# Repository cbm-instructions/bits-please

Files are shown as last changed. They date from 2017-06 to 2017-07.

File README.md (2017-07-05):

# bits-please | PlayTable
<div>
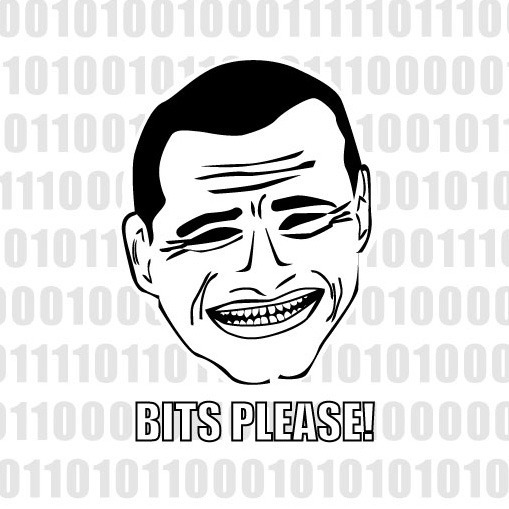
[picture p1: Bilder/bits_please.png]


</div>

## Einleitung
Der PlayTable ist ein Unterhaltungs-/Freizeitgegenstand und wurde von dem Team bits-please entwickelt. Es handelt sich hierbei um einen kleinen Tisch, in dem eine Matrix aus Pixel integriert ist, welche aufleuchten können. Es können bis zu zwei Leuten mit dem Tisch interagieren. Der PlayTable lässt jedes Gamerherz höher schlagen und dient für den Stressabbau des Hochschulalltags und den Zusammenschluss von Studierenden und Mitarbeitern.
 
Der PlayTable kann klassische Arcade-Games wie Tetris oder Pong aufweisen oder einfach nur als Dekoration für den Raum dienen, indem verschiedenste Bilder oder Animationen angezeigt werden.
 
Mit den zwei dazugehörigen Controllern macht das interagieren des Playtable gleich viel mehr Spaß!

### Challenge
Die Welt ist immer im Wandel und entwickelt sich immer weiter. So kommen auch neue Begriffe zu stande wie “Smart City”, der in aller Munde ist. Demzufolge soll es Universitäten geben, von denen man behaupten kann, dass sie eine “Smart University” sind. Die Hochschule Mannheim soll natürlich auch mit der Zeit gehen, weswegen uns die folgende Challenge gestellt wurde:
 
**Wie könnten Menschen in der „Smart HS Mannheim“ durch deren intelligente Geräte und Objekte dabei unterstützt werden angenehmer und spielerischer zu arbeiten?**
 
Aus diesem Grund haben wir uns für die Entwicklung eines “Smart Furniture” entschieden, nämlich für die Entwicklung des PlayTables.

### Point of View
Wie können wir den Studierenden helfen den Hochschulalltag entspannter und kreativer zu gestalten?

## Material und Werkzeug
 
### Material
* Schrumpfschlauch
* Diverse Kabel
* Kabelbinder
* Lötzinn
* Holzleim (Im Idealfall schnelltrocknend)
 
### Werkzeuge
* Bohrer
* Fräsbohrer 
* Lötkolben
* Abisolierzange
* Heißluftgebläse
* Heißklebepistole
* Schraubendreher Kreuzschlitz 
* Gehrungssäge
* Stichsäge
* Lasercutter
* Seitenschneider
* Schere
* Teppichbodenmesser
 
### Elektronik
* Arduino Mega
* Netzteil 5v,30A z.B. ATX-Netzteil 300W 
* Stromkabel Schuko auf Kaltgerätestecker
* 2x Female USB Kabel
* Schrumpfschlauch diverse Größen
* Lötzinn bleifrei
* Klebesockel
* Kabelbinder
* 4 x Widerstände 1.5K Ohm

### Tisch
* Kantholz (34mm x 34mm) benötogte Länge insgesamt 10 x 65 cm
* Spanplatte(65cm x 65cm , Stärke 12mm)
* Plexiglasplatte (65cm x 65cm,Lichtdurchlässigkeit 79%)
* Spaxschrauben 4mm x 60 mm (Für Rahmen)
* Spaxschrauben 3mm x 30 mm (Für Tischplatte)

### Matrix
* 3x Hochdichte Faserplatte (600mm x 45mm x 3mm)
* LED Stripes (60 LED's / m) zugeschnitten zu 16 Stripes a' 32 LED's 
 
### Controller
* Hochdichte Faserplatte (600mm x 45mm x 3mm)
* 8x 16mm Ø Buttons (Bspw von [Exp-Tech](http://www.exp-tech.de/16mm-panel-mount-momentary-pushbutton-yellow))
* 14 Magneten (5mm x 2,5mm x 2,5mm)
* 2 USB Kabel (2m)

## Bauanleitung

### Tischunterkonstruktion



Bauen des Tischs: [Anleitung](https://github.com/cbm-instructions/bits-please/blob/master/Tisch/README.md)

### Matrix

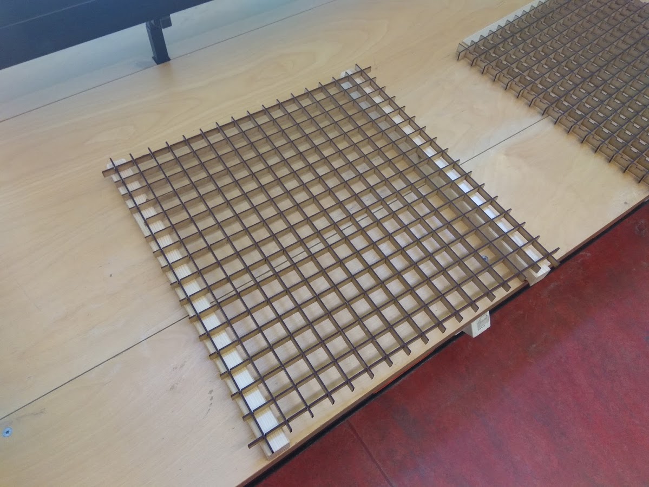
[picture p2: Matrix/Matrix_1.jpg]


Anfertigen der Matrix mit dem Lasercutter: [Anleitung](https://github.com/cbm-instructions/bits-please/blob/master/Matrix/README.md)

### Controller

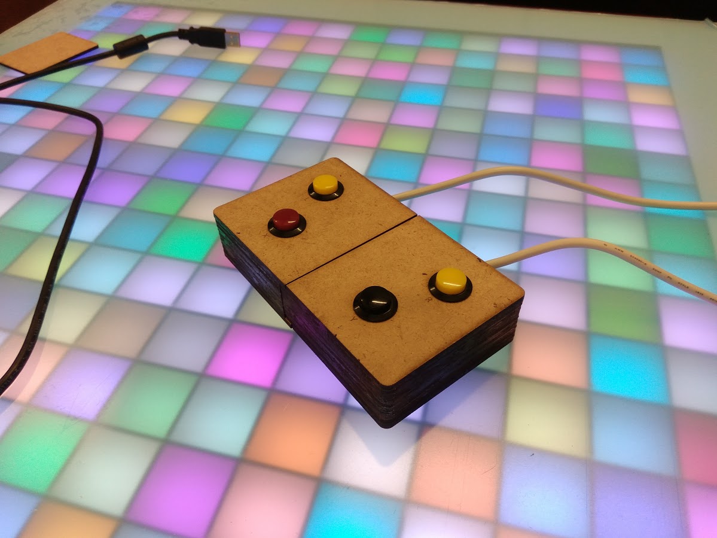
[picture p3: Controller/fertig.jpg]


Anfertigen des Controllers: [Anleitung](https://github.com/cbm-instructions/bits-please/blob/master/Controller/README.md)

### Elektronik

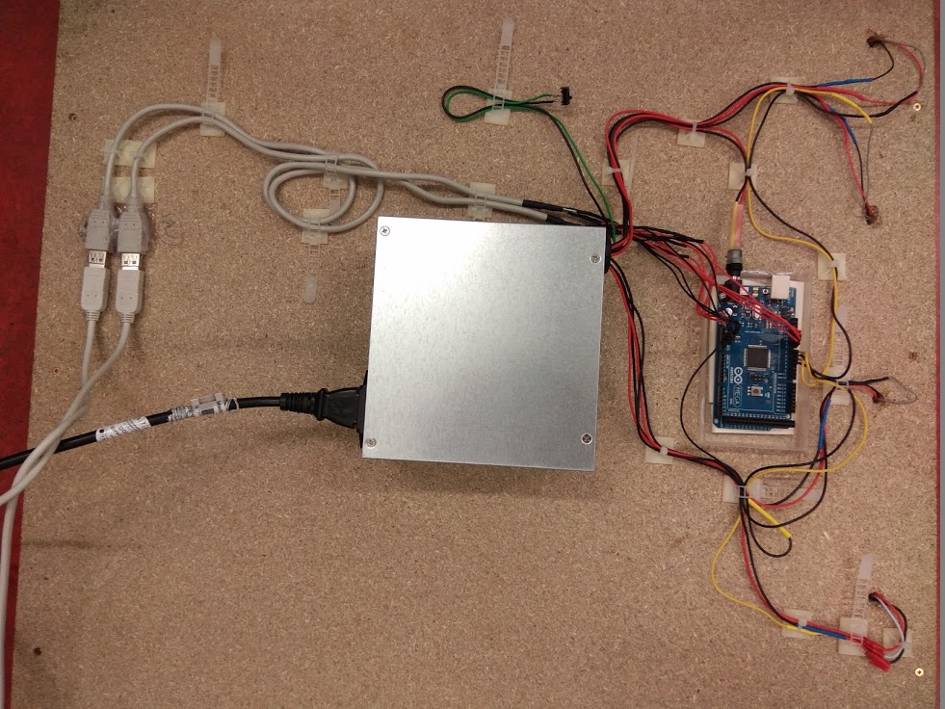
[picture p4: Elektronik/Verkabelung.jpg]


Anleitung zur Elektronik: [Anleitung](https://github.com/cbm-instructions/bits-please/blob/master/Elektronik/README.md)

### Finish

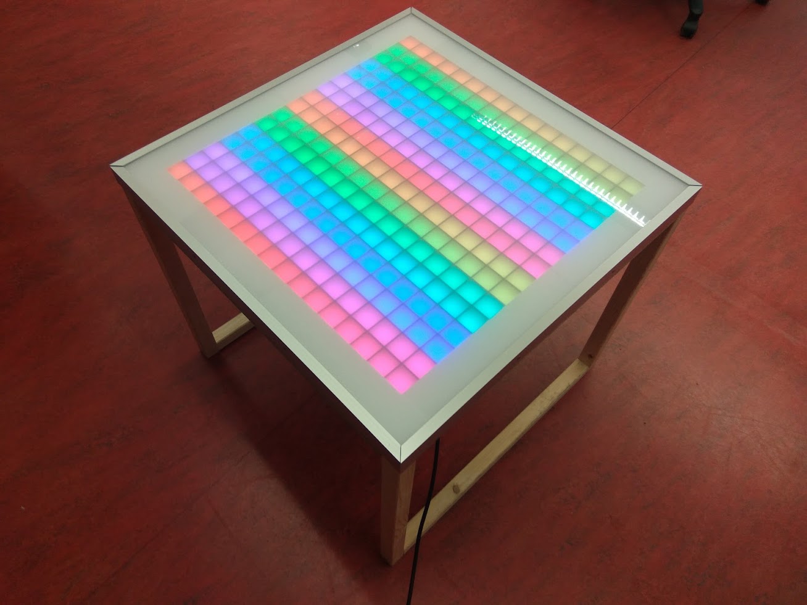
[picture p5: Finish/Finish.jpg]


Fertigstellen des Tischs: [Anleitung](https://github.com/cbm-instructions/bits-please/blob/master/Finish/README.md)

### Code
Die verwendete .ino Datei gibt's hier: [CBM.ino](https://github.com/cbm-instructions/bits-please/blob/master/Code/CBM.ino)<br>

Wer nur die Umsetzungen der einzelnen Spiele möchte findet diese hier:<br>

**Spiele**<br>
* Pong: [Pong](https://github.com/cbm-instructions/bits-please/blob/master/Code/Pong/Pong.c)<br>
* Tetris: [Tetris](https://github.com/cbm-instructions/bits-please/blob/master/Code/Tetris/Tetris.c)<br>  
* Snake: [Snake](https://github.com/cbm-instructions/bits-please/blob/master/Code/Snake/Snake.c)<br>

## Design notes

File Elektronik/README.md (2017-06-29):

Zum öffnen und bearbeiten des Schaltplans wird das Tool "Fritzing" benötigt. 
http://fritzing.org/download/ 
# Elektronik

## Schaltplan
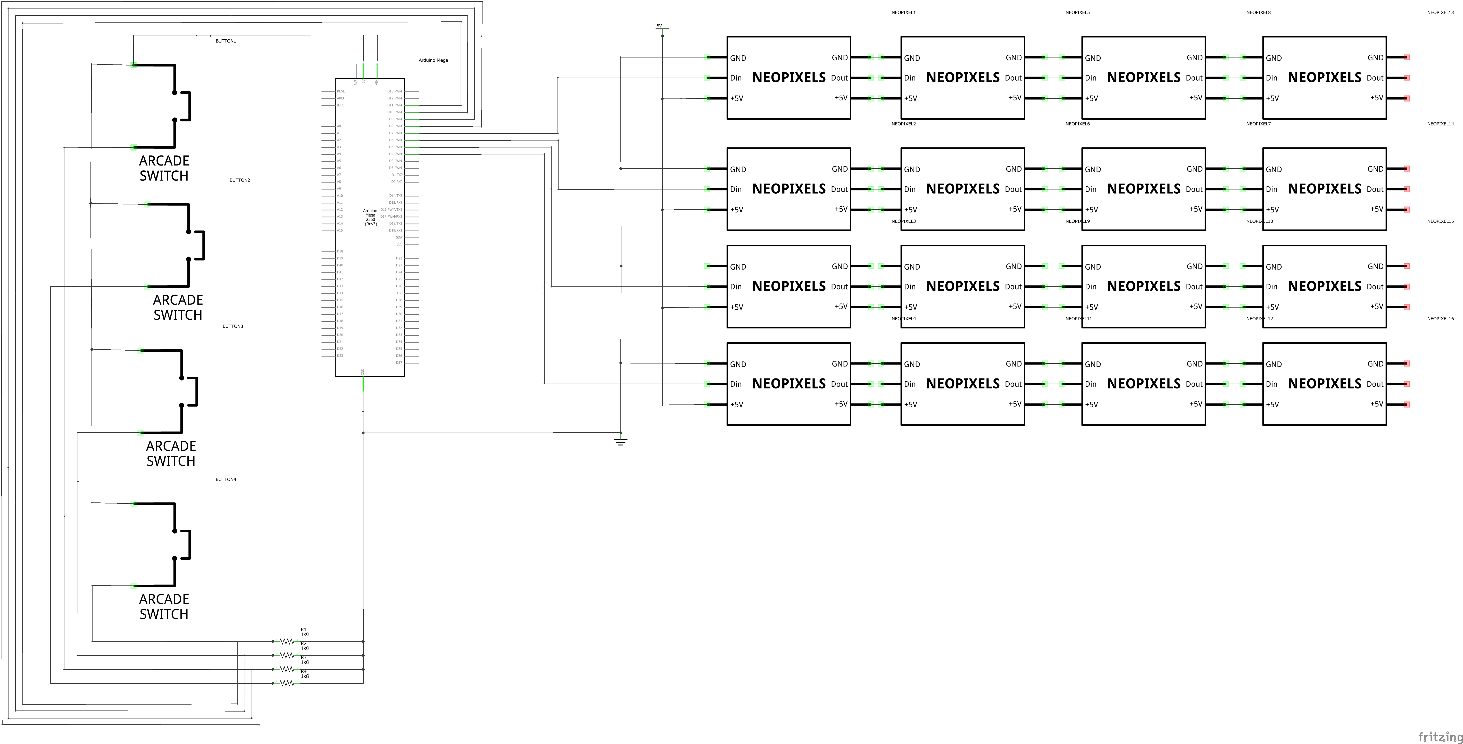
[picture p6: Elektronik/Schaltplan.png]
<br>

Der Schaltplan ist hier zu finden: [Fritzing-File](https://github.com/cbm-instructions/bits-please/blob/master/Schaltplan/Schaltplan.fzz), [Bild](https://github.com/cbm-instructions/bits-please/blob/master/Schaltplan/Schaltplan.png)

## Ansteuerung der LED Stripes
Um alle 16 LED-Stripes ansteuern zu können müssen diese zu vier Viererblöcken mit je 4x32 LED'S(32 LED's = 1 LED-Stripe) verlötet werden. Diese viererblöcke werden jeweils über einen Arduino Ausgang, eine 5V Spannungsversorgung und ein Masserkabel verdrahtet.(Siehe Schaltplan)

<br>

## Stromversorgung 

### AdaFruit NeoPixel am Arduino Mega
Auf die Stromversorgung der einzelnen Pixel muss geachtet werden. <br>
Ein einzelner NeoPixel kann **20mA bis zu 60mA** Strom ziehen, je nach der Einstellung in der Software.

Da wir bei einer 16x16 Pixel Matrix, wobei jeder einzelner Pixel zwei LED NeoPixel besitzt, wird der Strombedarf wie folgt berechnet:<br>

**16 LED Stripes mit jeweils 32 Neopixel, was uns insgesamt auf 512 NeoPixel bringt.**<br>
**Das heißt der Strombedarf liegt bei: 10240mA - 30720mA ~ 10,24A - 30,72A**

### Netzteil
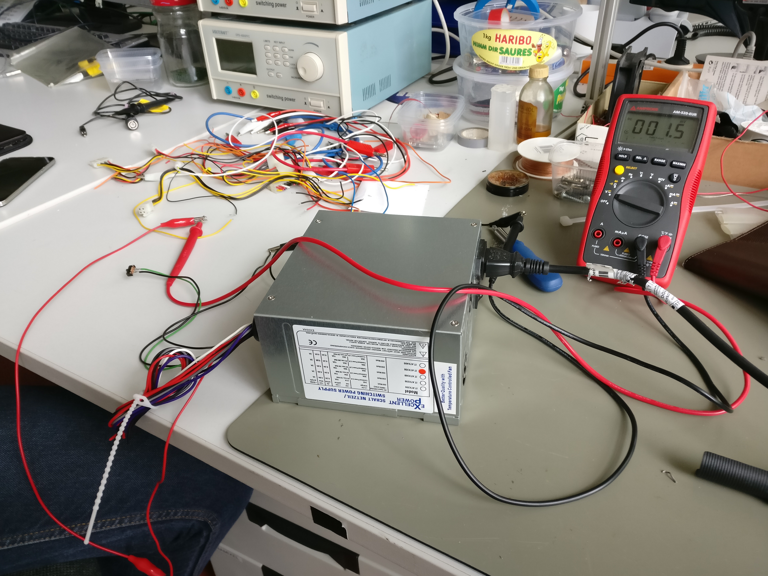
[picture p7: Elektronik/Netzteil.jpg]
<br>

Bei der Verwendung eines ATX Computer Netzteils, werden die nicht verwendeten Kabel entfernt. Benötigt werden nur die roten (5V) Kabel und die schwarzen (Masse)kabel. Das Grüne Kabel (PS_ON) muss mit einem schwarzen Massekabel kurzgeschlossen werden.<br>

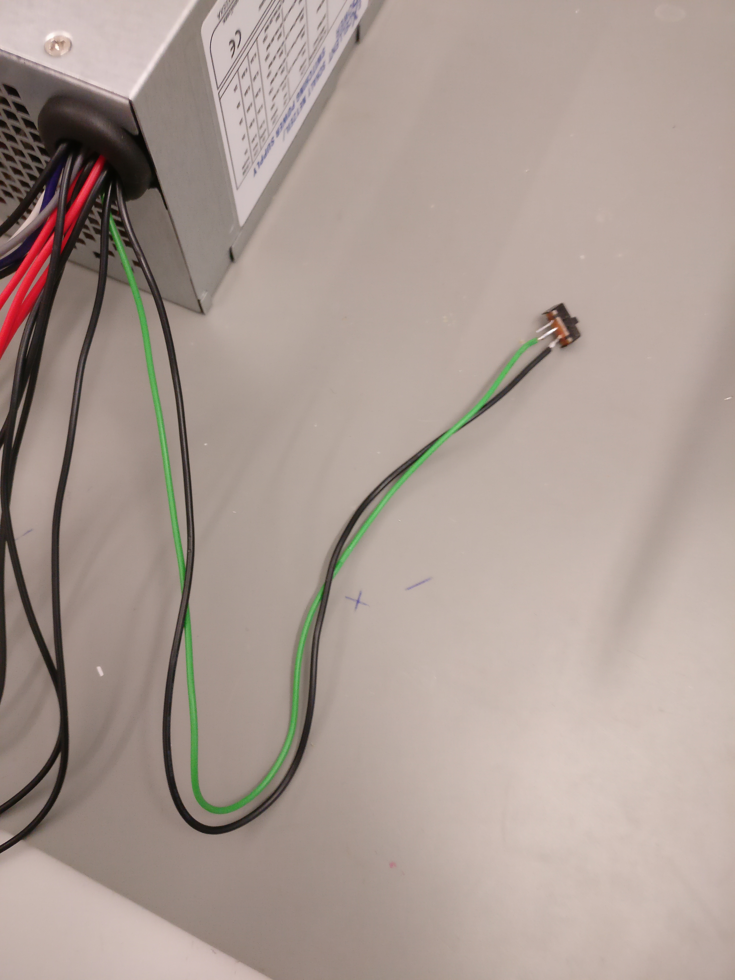
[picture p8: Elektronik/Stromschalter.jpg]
<br>

Die verlöteten Kabel mithilfe von Klebesockel und Kabelbinder an der Tisch Unterseite montieren. Netzteil an unterseite schrauben oder festkleben. Arduino ebenfalls festkleben. 

<br>

Lötstellen und offene Kabelenden mit Schrumpfschlauch isolieren!

<br>

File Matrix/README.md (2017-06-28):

## Matrix
### 1. Lasercutter Zuschnitte anlegen (3 Platten a 60x45cm)
Zum Download der [Illustratordateien](https://github.com/cbm-instructions/bits-please/blob/master/Matrix/Zuschnitt_Matrix.zip)

Dabei darauf achten, dass der Laser stark genug eingestellt ist, sonst können beim Ausbrechen Teile kaputt gehen.

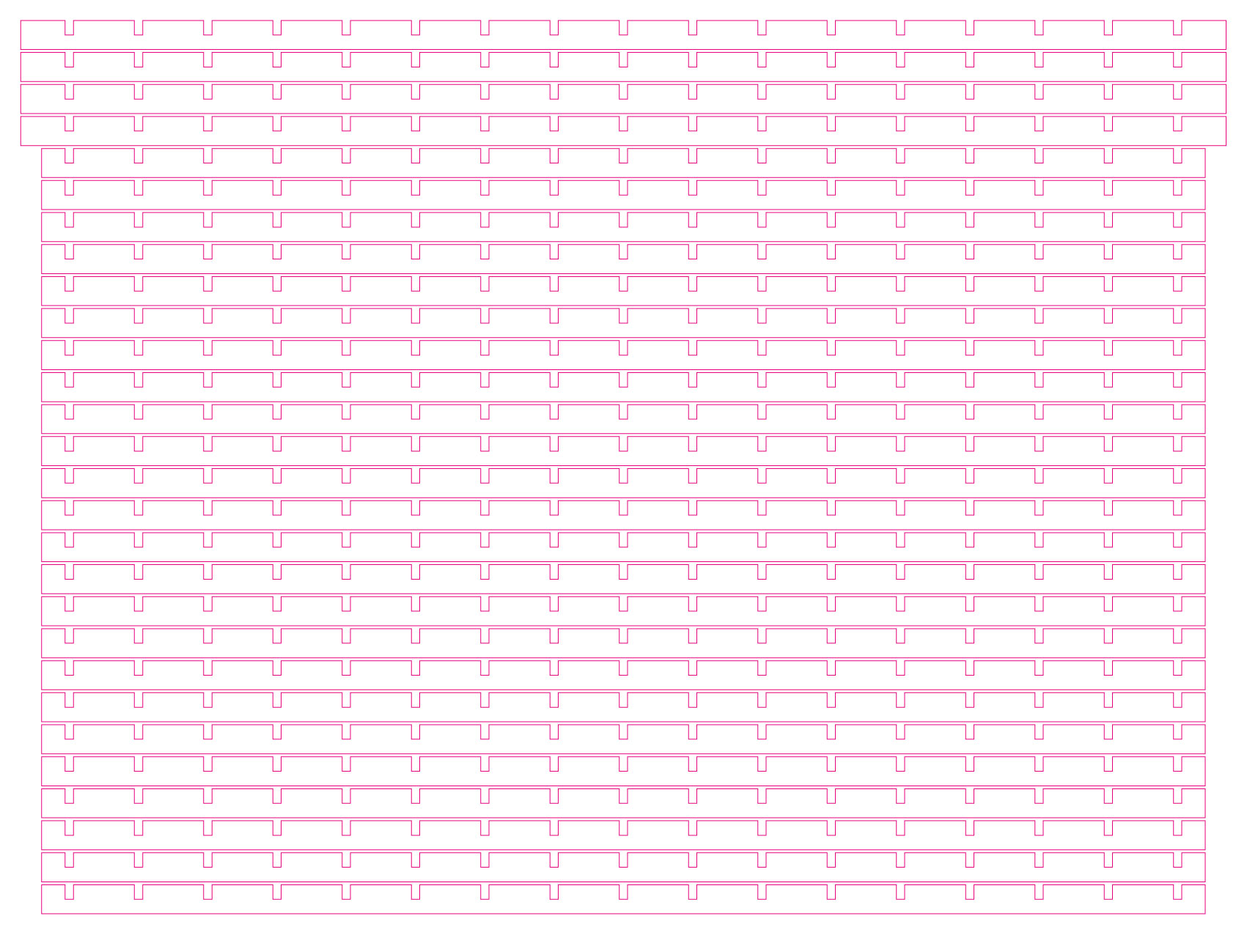
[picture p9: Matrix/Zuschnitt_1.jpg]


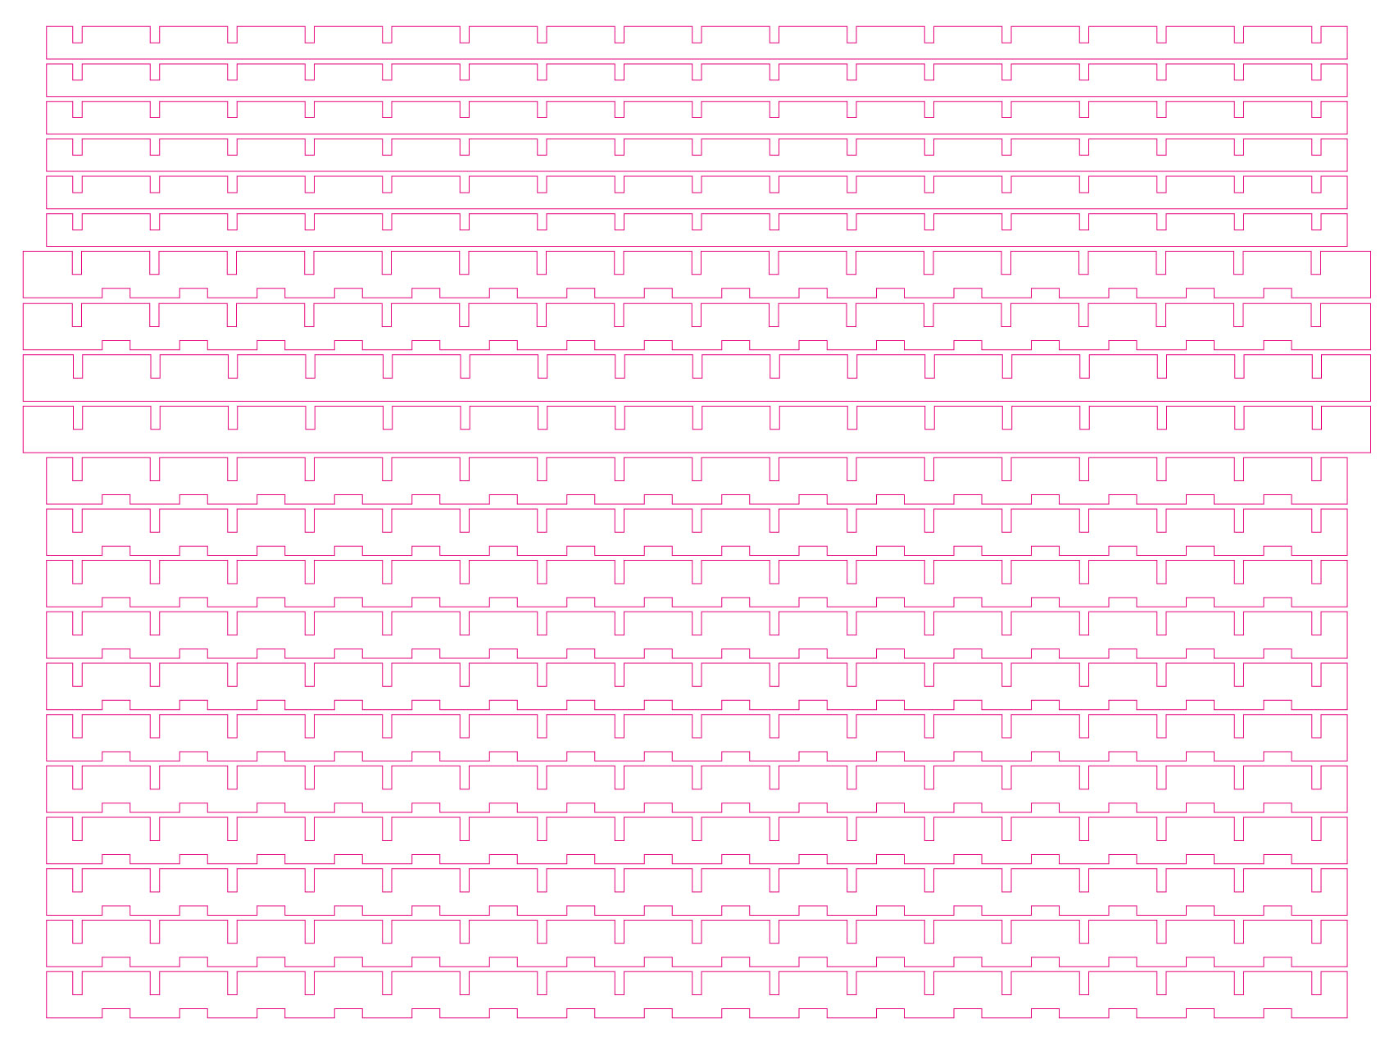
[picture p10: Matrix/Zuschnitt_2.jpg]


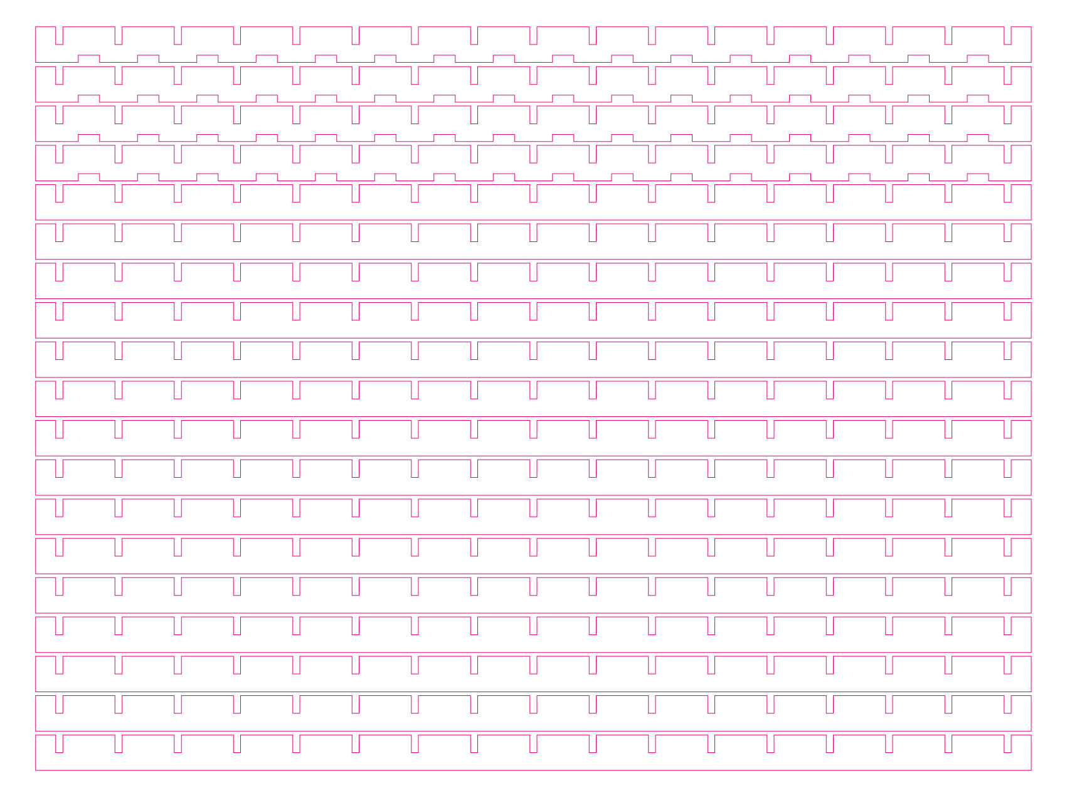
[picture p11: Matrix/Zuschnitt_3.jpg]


### 2. HDF Platten auf 60cm x 45cm zuschneiden
Oder direkt im Baumarkt auf die Größe zuschneiden lassen.

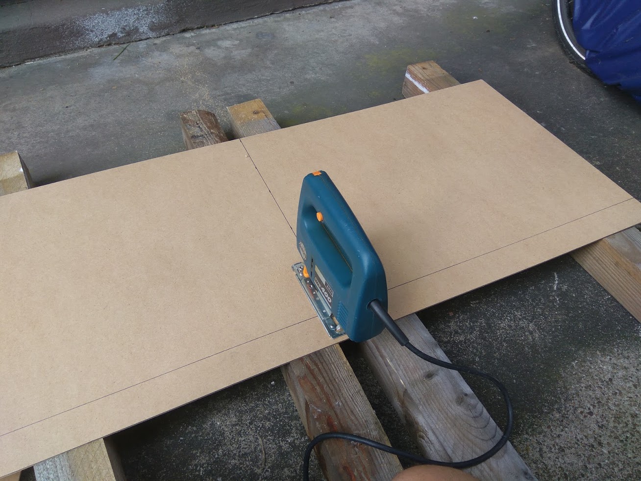
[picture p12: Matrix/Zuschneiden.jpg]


### 3. Die drei Zuschnitte mit einem Lasercutter zuschneiden

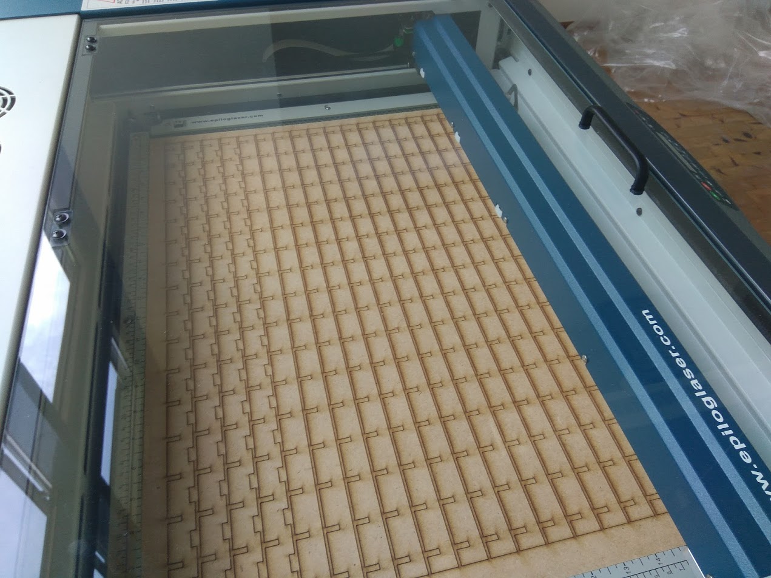
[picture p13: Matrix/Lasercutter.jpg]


### 4. Einzelteile ausbrechen

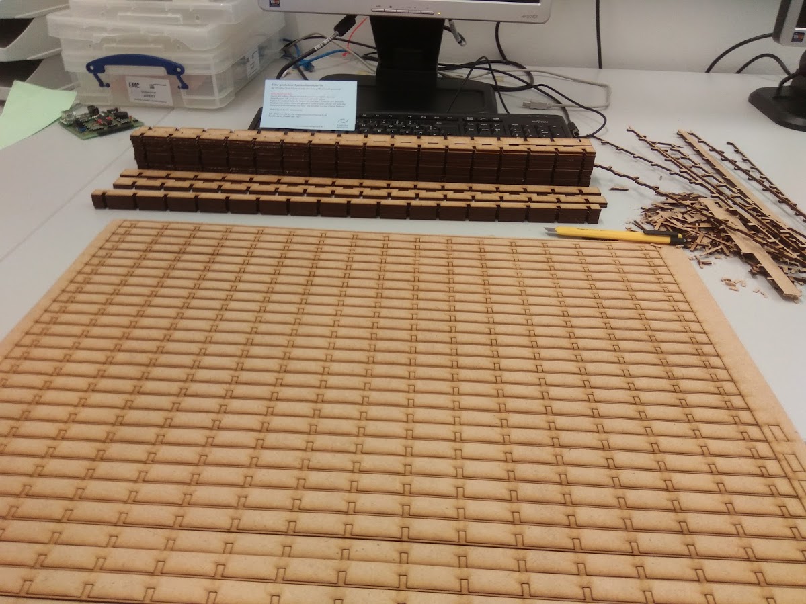
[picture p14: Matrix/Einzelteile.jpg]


### 5. Beide Matrizen zusammensetzen und an allen Eckpunkten mit Heißkleber verkleben
Dabei immer die zu verklebende Leiste anheben und in die Aussparungen den Heißkleber geben.
Nicht zu viel Heißkleber verwenden, da man sonst einzeln den Überschuss entfernen muss, da mann dies sonst später sieht.



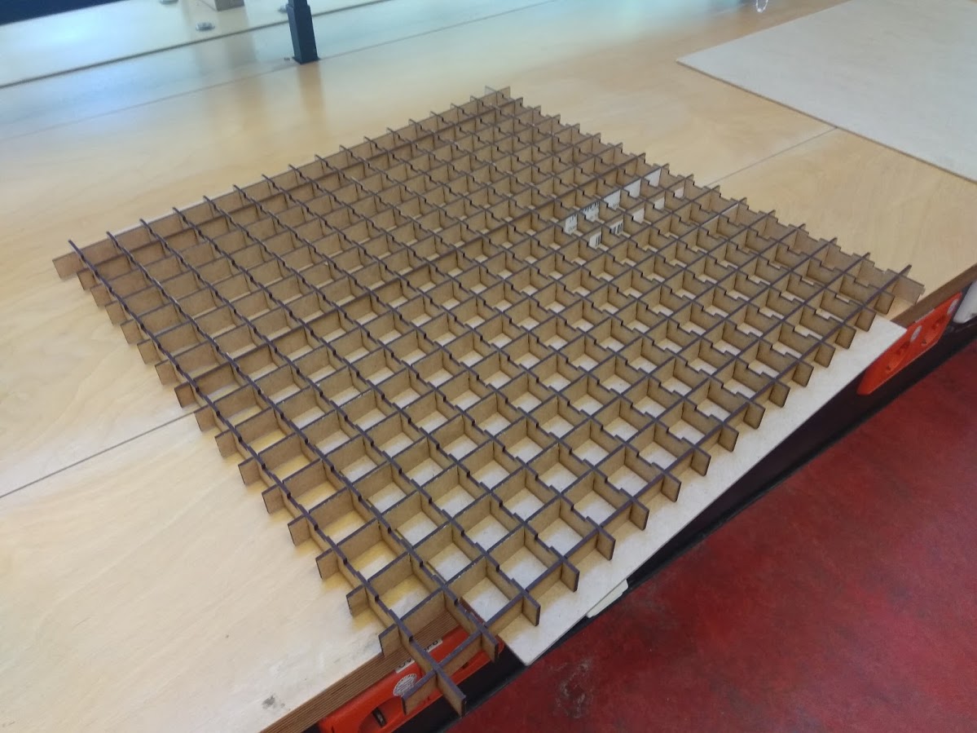
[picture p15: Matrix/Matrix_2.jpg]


### 6. Matrizen in den Tisch einsetzen

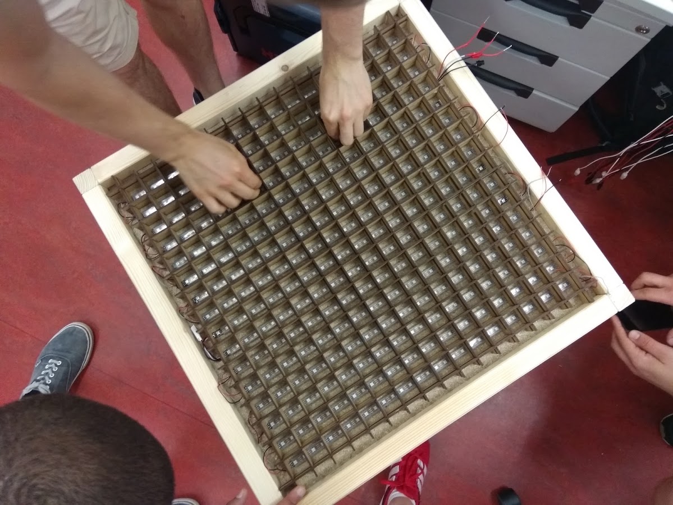
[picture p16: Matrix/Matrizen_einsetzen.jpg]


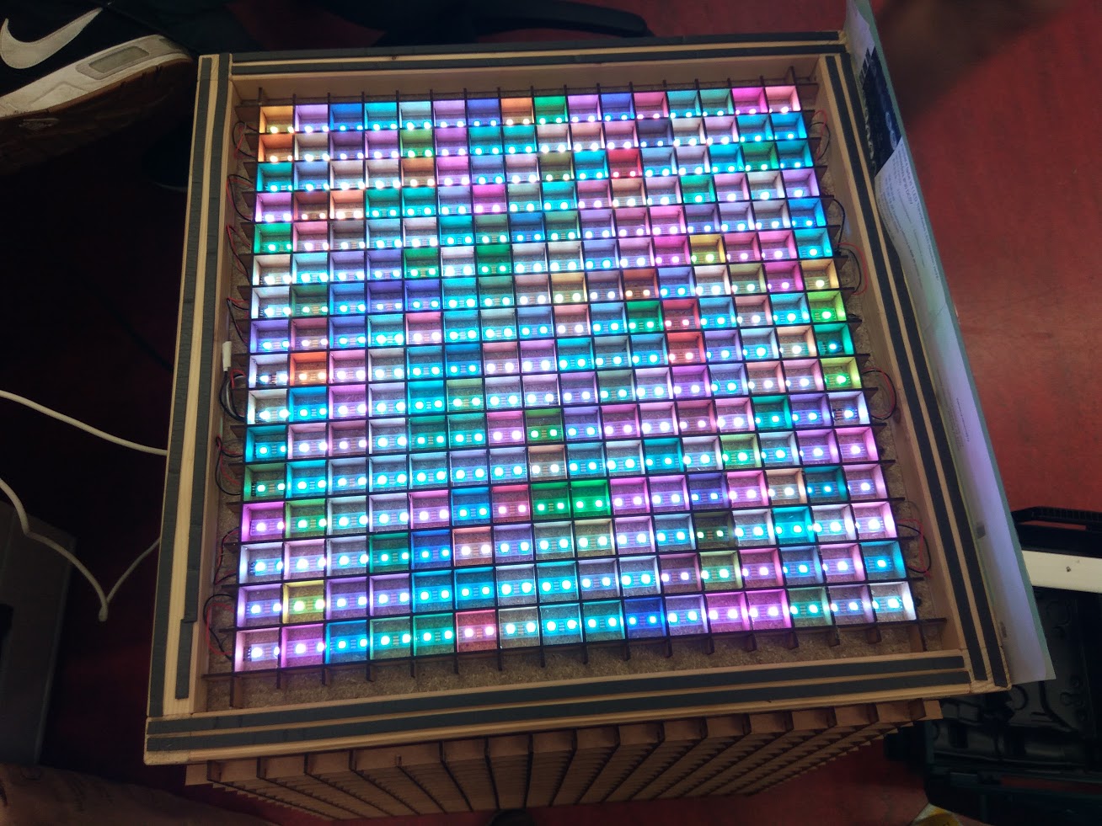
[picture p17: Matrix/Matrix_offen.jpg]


### 7. Zur idealen Diffusion zwei 55cm Brotpapierbahnen (weiß) zusammenkleben

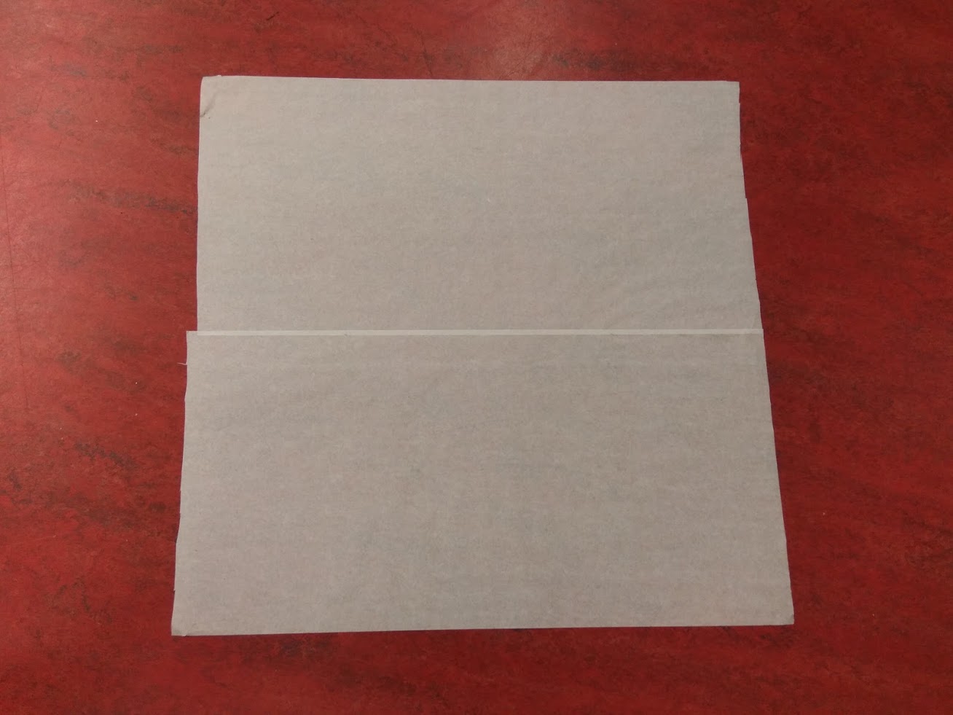
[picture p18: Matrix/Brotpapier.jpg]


### 8. Brotpapier zwischen beide Matrizen einlegen

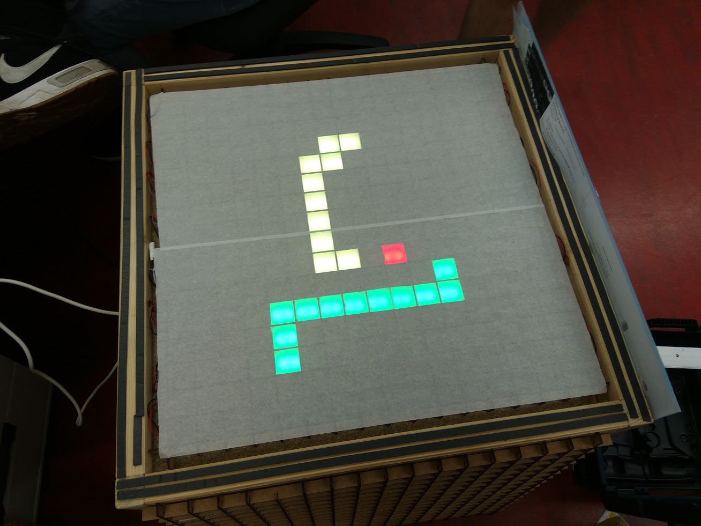
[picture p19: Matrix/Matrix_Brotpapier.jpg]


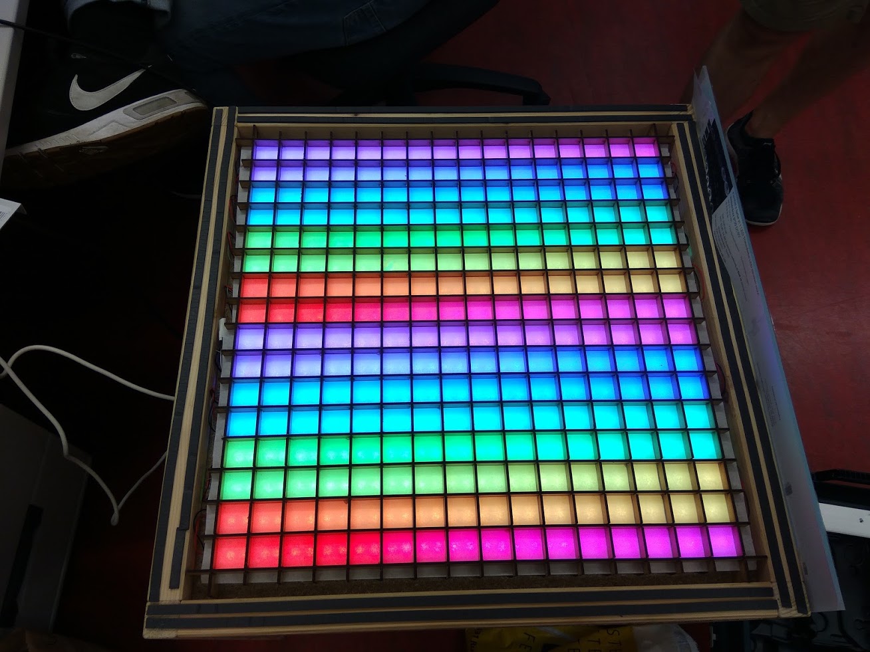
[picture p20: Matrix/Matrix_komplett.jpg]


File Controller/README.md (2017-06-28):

## Controller
### 1. Lasercutter Zuschnitt anlegen (1 Platte a 60x45cm)
[Illustratordatei](https://github.com/cbm-instructions/bits-please/blob/master/Controller/Zuschnitt_Controller.zip)

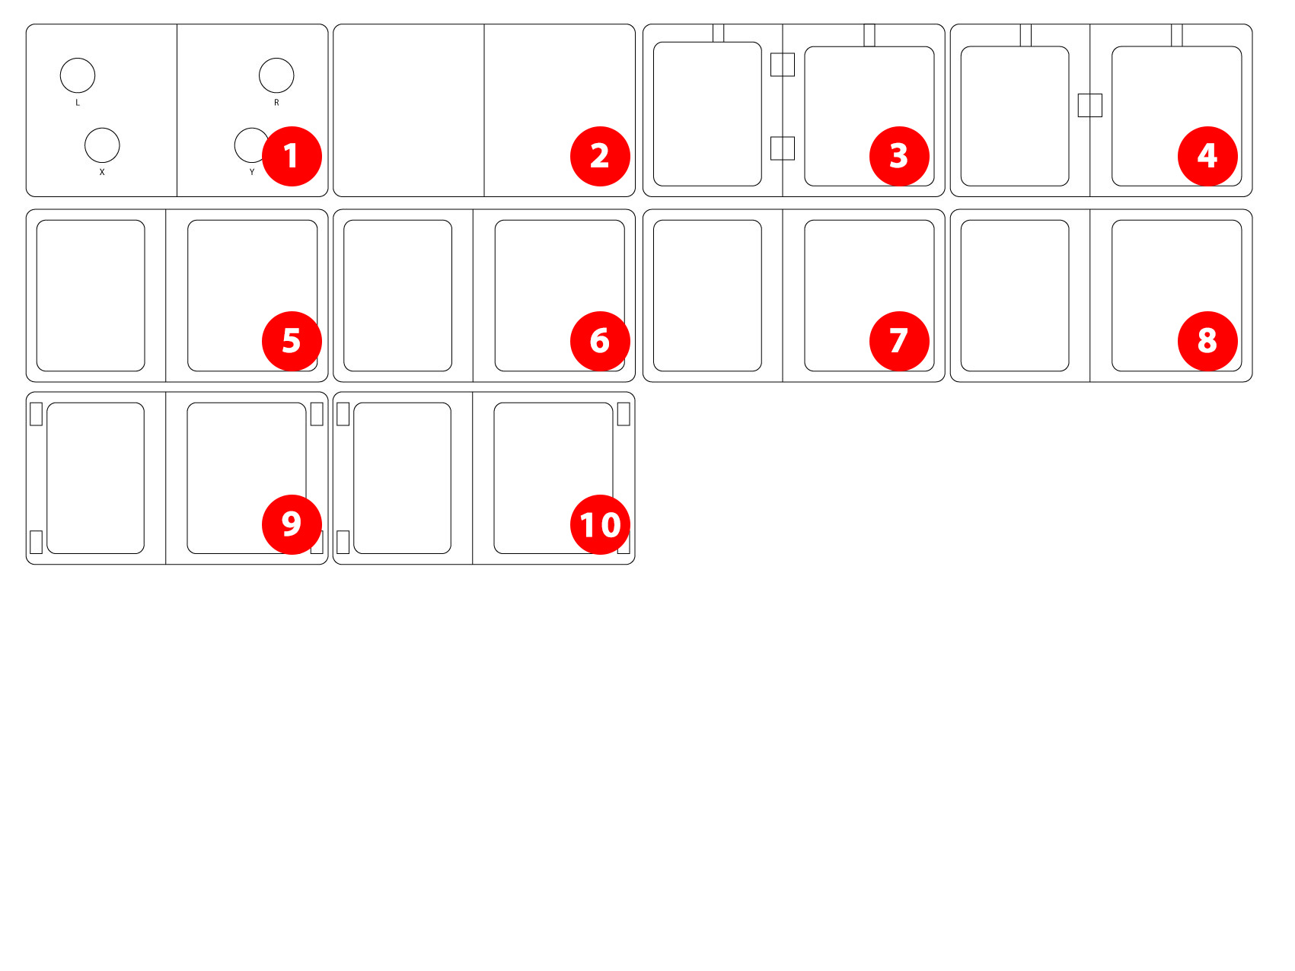
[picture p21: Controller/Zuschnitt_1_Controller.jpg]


### 2. Den Zuschnitt mit einem Lasercutter zuschneiden und Einzelteile ausbrechen

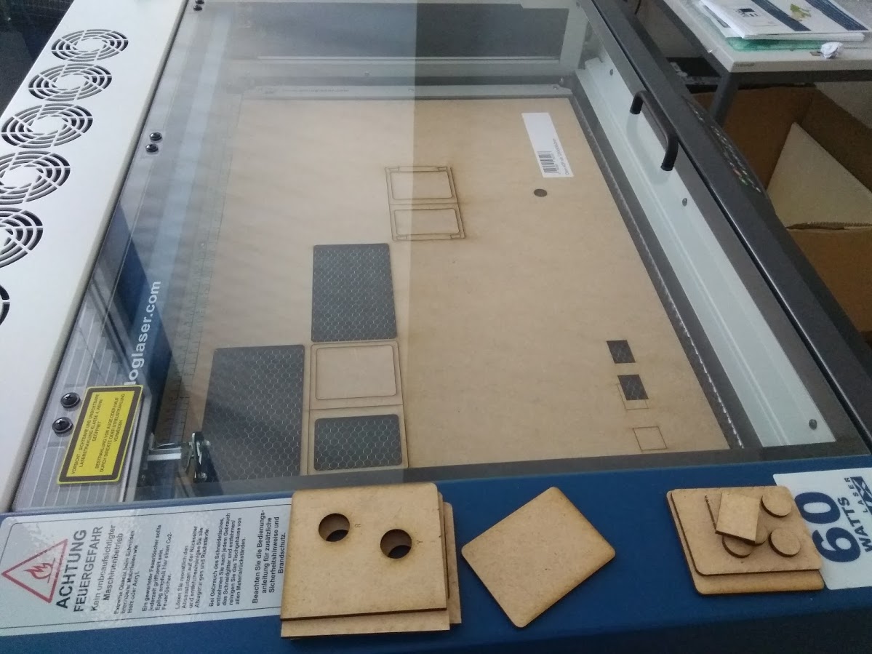
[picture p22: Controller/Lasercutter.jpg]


### 3. Die verschiedenen Schichten verleimen.
Der Boden: Teil 2 muss mit Teil 10 verleimt werden.
Der Oberteil muss (in Reihenfolge) verleimt werden aus den Teilen:
- Teil 1
- Teil 5
- Teil 6
- Teil 7
- Teil 3
- Teil 4
- Teil 8 
- Teil 9

Nach dem Verleimen mit Büchern beschweren oder mit Schraubzwingen zusammendrücken.

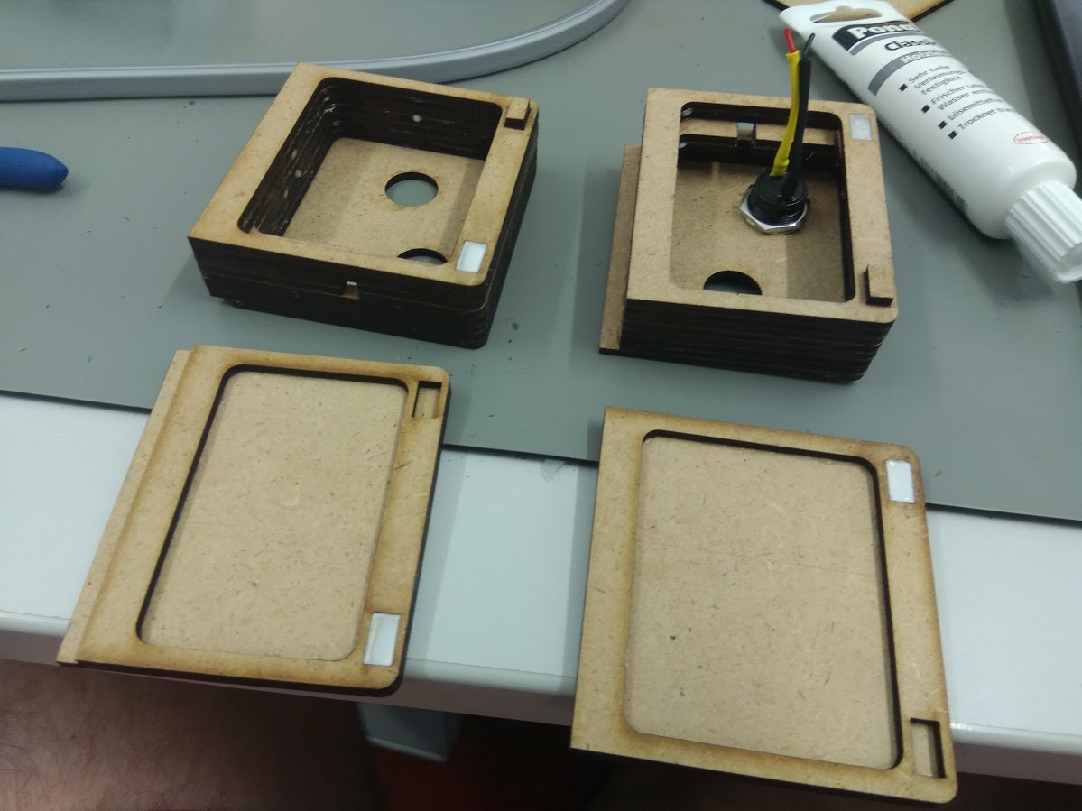
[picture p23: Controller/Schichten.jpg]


### 4. Die Aussparungen mit Magneten bestücken
- 6 Stück sind dafür gedacht, den Controller zusammen zu halten
- 8 Stück um die beiden Böden zusammen zu halten
- Unbedingt die Richtung der Polarisation beachten (Magnetenpaare vorher aneinander legen)

(Im Bild nur 4 an den Seiten zu sehen, da dies erst später geändert wurde)

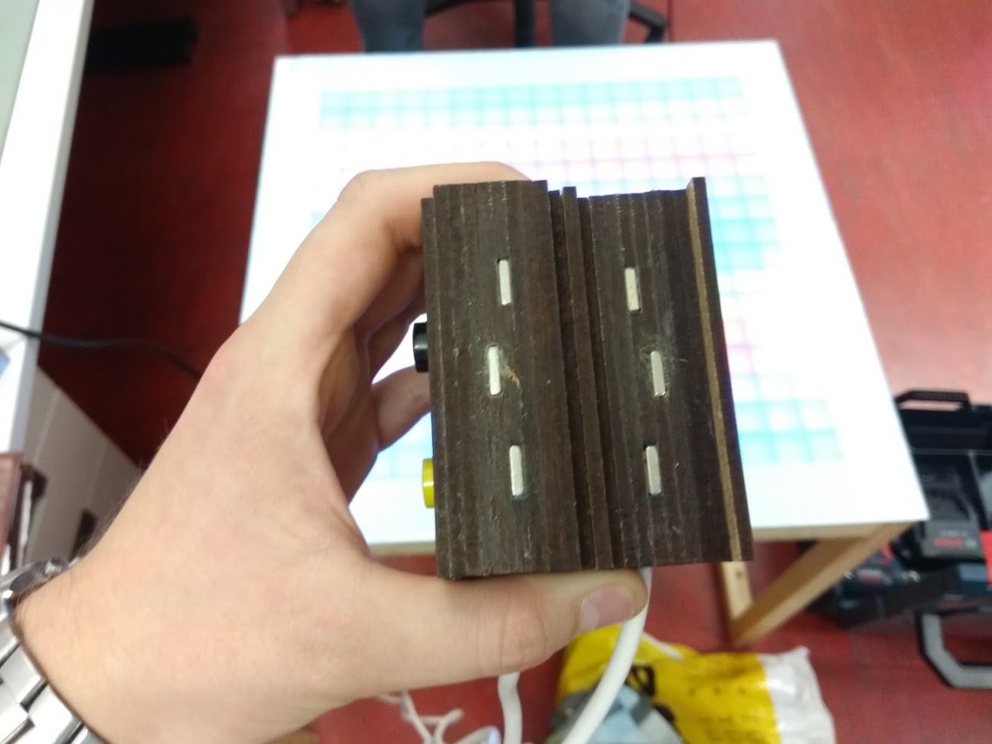
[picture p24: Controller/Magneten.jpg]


### 5. Buttons einsetzen

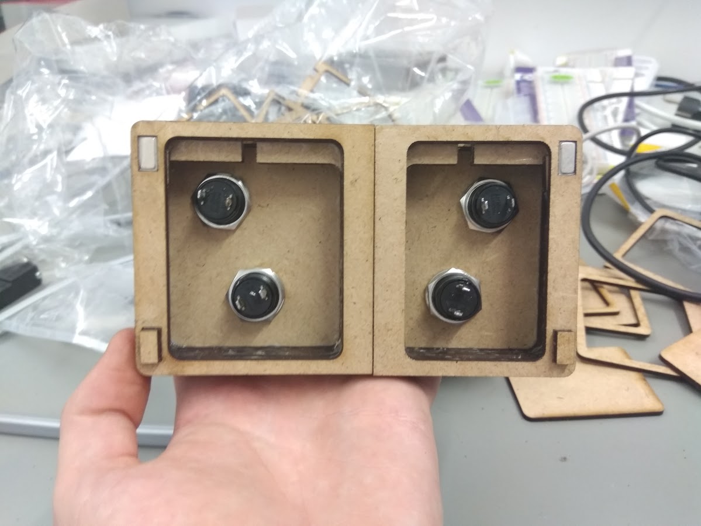
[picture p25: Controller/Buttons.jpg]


### 6. Buttons löten

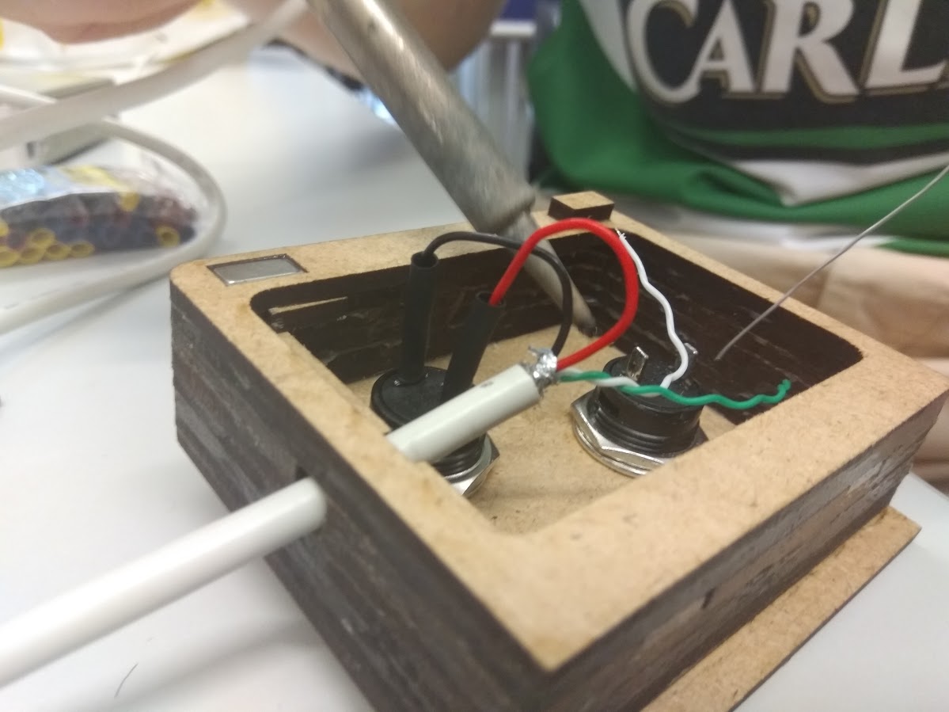
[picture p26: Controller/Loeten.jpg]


### 7. Kabel mit zwei Kabelbindern und Heißkleber sichern.

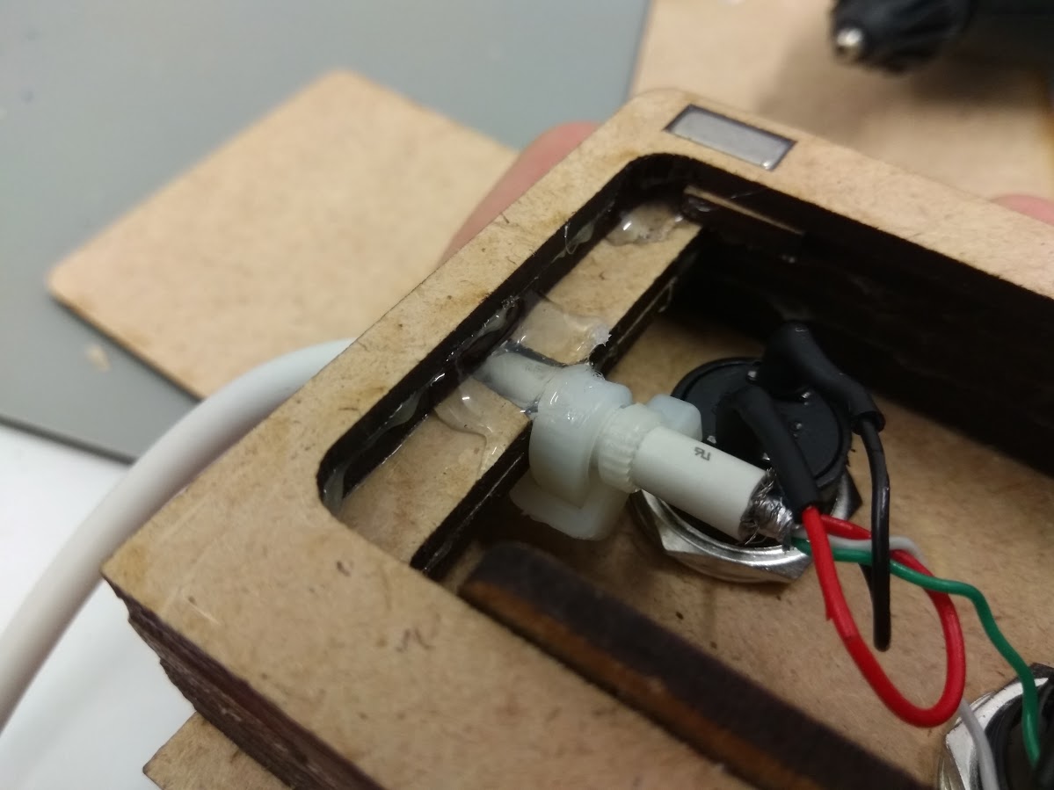
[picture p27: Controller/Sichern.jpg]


### 8. Alles zusammensetzen

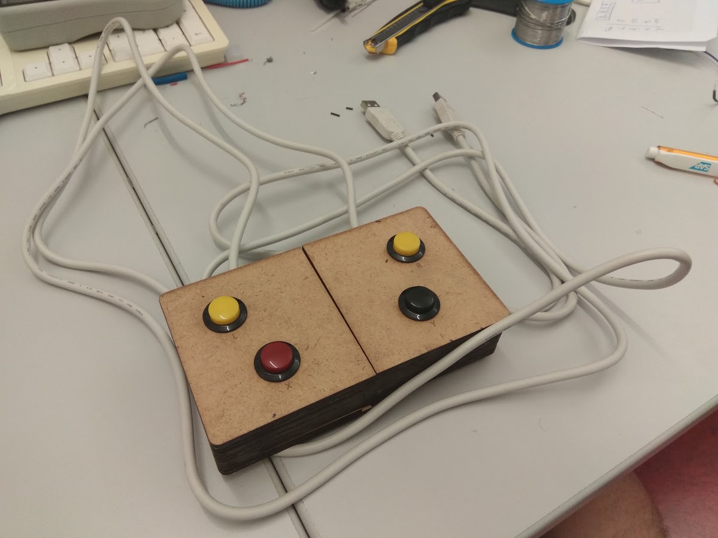
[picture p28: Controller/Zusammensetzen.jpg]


### 9. Anschließen - fertig!



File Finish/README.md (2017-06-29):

## Finish

### 1. L Leisten zuschneiden



### 2. Löcher bohren

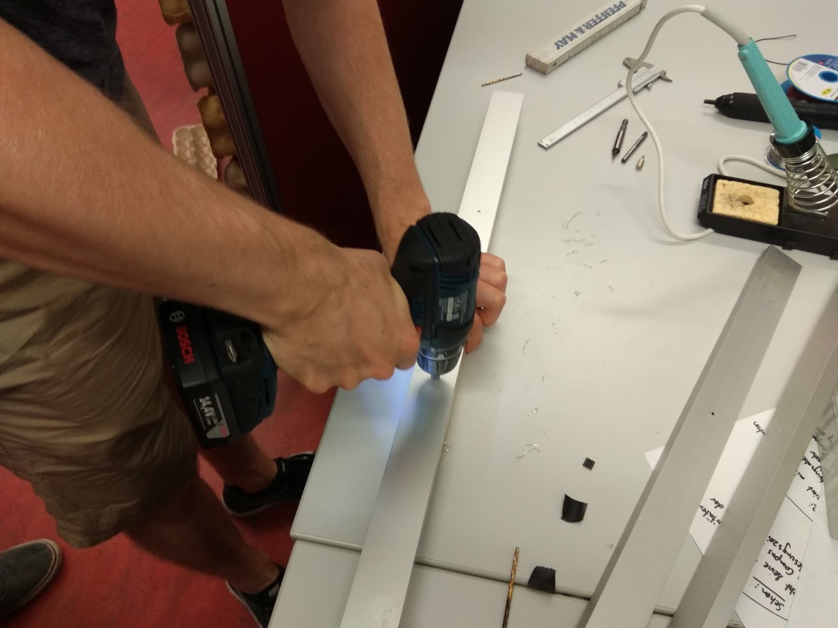
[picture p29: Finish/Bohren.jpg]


### 3. Löcher senken



### 4. Plexiglas aufsetzen
An den Rändern die Folie ab machen, aber nicht komplett.



### 5. Leisten anschrauben
Zuerst gegenüber, dann die anderen.
Noch nicht komplett anziehen, erst wenn alle Leisten verschraubt sind.



### 6. Feilen
Alle abstehenden Kanten abfeilen.



### 7. Zack fertig



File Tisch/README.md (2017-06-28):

## Tischunterkonstruktion

### 1. Unebenen Enden des Vierkantholzes absägen



### 2. Vierkantholz zuschneiden
Vierkantholz zu je 10 Stücken a 65 cm, mit einem möglichst feinen Sägeblatt, absägen. Achtung!! Erstes Stück als Messlatte für alle anderen Stücke verwenden.



### 3. Abschmiergeln
Grat an den Sägenenden jeweils mit Schmirgelpapier oder Feile 
entfernen



### 5. Bohren
Vier Tischfüsse mithilfe der Bohrschablonevorbohren. Dazu am besten in Schraubstock einspannen, um senkrecht einbohren zu können.
[Bohrschablone](https://github.com/cbm-instructions/bits-please/blob/master/Bilder/Bohrschablone.jpg)



### 6. Verschrauben
Vier Tischfüsse mit restlichen Stücken zu einem Rahmen verschrauben.



### 7. Aussparung sägen
Aussparung an den Ecken der Bodenplatte mit je 34mm x 34mm mithilfe einer Stichsäge aussägen.  



### 8. Platte einpassen
Eventuell die Ausparungen nachfeilen, und mit je 3 Schrauben pro Seite am Rahmen festschrauben.



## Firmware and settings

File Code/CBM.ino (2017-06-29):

// Complete programming of the PlayTable by Bits Please for CBM SS 2017
// Demomodus, Controls
#include <Adafruit_GFX.h>
#include <Adafruit_NeoPixel.h>
#ifdef __AVR__
  #include <avr/power.h>
#endif
#ifndef PSTR
 #define PSTR // Make Arduino Due happy
#endif

#define SIZE 16
#define WHITE strip_1.Color(255,255,255)
#define RED strip_1.Color(255,0,0)
#define YELLOW strip_1.Color(255,255,0)
#define GREEN strip_1.Color(0,255,0)
#define TEAL strip_1.Color(0,255,255)
#define BLUE strip_1.Color(0,0,255)
#define MAGENTA strip_1.Color(255,0,255)
#define MATRIX_GREEN strip_1.Color(0,253,0)
// which pins are connected to which controls/led strips
#define RIGHT 8
#define LEFT 10
#define DOWN 11
#define TURN 9
#define STRIP1 4
#define STRIP2 5
#define STRIP3 6
#define STRIP4 7

//Image Code colors
#define MARIO_RED strip_1.Color(255,10,10)
#define MARIO_BLUE strip_1.Color(0,0,255)
#define MARIO_BROWN strip_1.Color(51,25,0)
#define MARIO_HAUT strip_1.Color(255,178,102)
#define MARIO_KNOEPFE strip_1.Color(255,255,0)
//Image Stern colors
#define MARIO_STERN_INNENGELB strip_1.Color(255,255,51)

#define PONG_WIN_SCORE 5 // don't set this over 9
#define MAX_PONG_SPEED 2 // defines the delay in milliseconds between each calculated frame means: lower number, faster speed
#define SNAKE_START_SPEED 30 // if snake is too slow for you set this number lower to set a faster starting speed
#define ENABLE_DEMO_MODE 1 // set to 0 if you want to disable the automatic switching through modes
#define TABLE_BRIGHTNESS 100 // you can set this between 0 (not so useful) and 100 (awesome!). Will reduce power usage.

Adafruit_NeoPixel strip_1 = Adafruit_NeoPixel(128, STRIP1, NEO_GRB + NEO_KHZ800);
Adafruit_NeoPixel strip_2 = Adafruit_NeoPixel(128, STRIP2, NEO_GRB + NEO_KHZ800);
Adafruit_NeoPixel strip_3 = Adafruit_NeoPixel(128, STRIP3, NEO_GRB + NEO_KHZ800);
Adafruit_NeoPixel strip_4 = Adafruit_NeoPixel(128, STRIP4, NEO_GRB + NEO_KHZ800);

// Images
byte image_pong[16][16]={
  {0,0,0,1,1,1,0,0,0,0,1,1,1,0,0,0},
  {0,0,0,1,0,1,0,0,0,0,0,0,1,0,0,0},
  {0,0,0,1,0,1,0,0,0,0,1,1,1,0,0,0},
  {0,0,0,1,0,1,0,0,0,0,1,0,0,0,0,0},
  {0,0,0,1,1,1,0,0,0,0,1,1,1,0,0,1},
  {0,0,0,0,0,0,0,0,0,0,0,0,0,0,0,1},
  {0,0,0,0,0,0,0,0,0,0,0,0,0,0,0,1},
  {0,0,0,0,0,0,0,0,0,0,0,0,0,0,0,0},
  {0,0,0,0,0,0,0,0,0,0,0,0,1,0,0,0},
  {1,0,0,0,0,0,0,0,0,0,0,0,0,0,0,0},
  {1,0,0,0,0,0,0,0,0,0,0,0,0,0,0,0},
  {1,0,0,0,0,0,0,0,0,0,0,0,0,0,0,0},
  {0,0,0,0,0,0,0,0,0,0,0,0,0,0,0,0},
  {0,0,0,0,0,0,0,0,0,0,0,0,0,0,0,0},
  {0,0,0,0,0,0,0,0,0,0,0,0,0,0,0,0},
  {0,0,0,0,0,0,0,0,0,0,0,0,0,0,0,0}
};

byte image_tetris[16][16]={
  {0,0,0,0,0,0,0,0,0,0,0,0,0,0,0,0},
  {0,0,0,0,0,0,0,0,0,0,0,0,0,0,0,0},
  {0,0,0,0,0,0,0,0,0,0,0,0,0,0,0,0},
  {0,0,0,0,0,0,0,0,0,0,0,0,0,0,0,0},
  {0,0,0,0,0,0,1,0,0,0,0,0,0,0,0,0},
  {0,0,0,0,0,0,1,0,0,0,0,0,0,0,0,0},
  {0,0,0,0,0,0,1,0,0,0,0,0,0,0,0,0},
  {0,0,0,0,0,0,1,0,0,0,0,0,0,0,0,0},
  {0,0,0,0,0,0,0,0,0,0,0,0,0,0,0,0},
  {0,0,0,0,0,0,0,0,0,0,0,0,0,0,0,0},
  {0,0,0,0,0,0,0,0,0,0,0,0,0,0,0,0},
  {0,0,0,0,0,0,0,3,0,0,0,0,0,0,0,0},
  {0,0,4,0,0,7,0,3,3,0,5,3,3,3,7,7},
  {2,4,4,3,7,7,0,3,6,5,5,4,4,3,7,6},
  {2,4,3,3,4,7,0,6,6,5,4,4,5,5,7,6},
  {2,2,3,4,4,4,0,6,2,2,2,2,5,5,6,6}
};

byte image_snake[16][16]={
  {0,0,0,0,0,0,0,0,0,0,0,0,0,0,0,0},
  {0,0,0,0,0,0,0,0,0,0,0,0,0,0,0,0},
  {0,0,0,0,1,0,0,0,0,0,0,0,0,0,0,0},
  {0,0,0,0,1,0,0,0,0,0,0,0,0,0,0,0},
  {0,0,0,0,1,1,1,1,1,1,1,1,0,0,0,0},
  {0,0,0,0,0,0,0,0,0,0,0,1,0,0,0,0},
  {0,0,0,0,0,0,2,2,0,3,0,0,0,0,0,0},
  {0,0,0,0,0,0,2,0,0,0,0,0,0,0,0,0},
  {0,0,0,0,0,0,2,0,0,0,0,0,0,0,0,0},
  {0,0,0,0,0,0,2,0,0,0,0,0,0,0,0,0},
  {0,0,0,0,0,0,2,0,0,0,0,0,0,0,0,0},
  {0,0,0,0,0,0,2,2,0,0,0,0,0,0,0,0},
  {0,0,0,0,0,0,0,2,2,0,0,0,0,0,0,0},
  {0,0,0,0,0,0,0,0,0,0,0,0,0,0,0,0},
  {0,0,0,0,0,0,0,0,0,0,0,0,0,0,0,0},
  {0,0,0,0,0,0,0,0,0,0,0,0,0,0,0,0}
};

byte image_mario[16][16]={
  {0,0,0,0,0,1,1,1,1,1,0,0,0,0,0,0},
  {0,0,0,0,1,1,1,1,1,1,1,1,1,0,0,0},
  {0,0,0,0,2,2,2,4,4,3,4,0,0,0,0,0}, // 1 Rot
  {0,0,0,2,4,2,4,4,4,3,4,4,4,0,0,0}, // 2 Braun
  {0,0,0,2,4,2,2,4,4,4,3,4,4,4,0,0}, // 3 Schwarz
  {0,0,0,0,2,4,4,4,4,3,3,3,3,0,0,0}, // 4 Gelb/Hautfarben
  {0,0,0,0,0,4,4,4,4,4,4,0,0,0,0,0}, // 5 Blau
  {0,0,0,0,1,1,5,1,1,5,1,1,0,0,0,0},
  {0,0,0,1,1,1,5,1,1,5,1,1,1,0,0,0},
  {0,0,1,1,1,1,5,5,5,5,1,1,1,1,0,0},
  {0,0,4,4,1,5,8,5,5,8,5,1,4,4,0,0}, //8 Knoepfe
  {0,0,4,4,4,5,5,5,5,5,5,4,4,4,0,0},
  {0,0,4,4,5,5,5,5,5,5,5,5,4,4,0,0},
  {0,0,0,0,5,5,5,0,0,5,5,5,0,0,0,0},
  {0,0,0,2,2,2,0,0,0,0,2,2,2,0,0,0},
  {0,0,2,2,2,2,0,0,0,0,2,2,2,2,0,0}
}; 

byte image_mario_stern[16][16]={
  {0,0,0,0,0,0,0,3,3,0,0,0,0,0,0,0}, //3 Schwarz
  {0,0,0,0,0,0,3,7,7,3,0,0,0,0,0,0}, //7 Hautfarben Gelb
  {0,0,0,0,0,0,3,7,7,3,0,0,0,0,0,0},
  {0,0,0,0,0,3,7,7,7,7,3,0,0,0,0,0},
  {3,3,3,3,3,3,7,7,7,7,3,3,3,3,3,3},
  {3,7,7,7,7,7,7,7,7,7,7,7,7,7,7,3}, 
  {0,3,7,7,7,7,3,7,7,3,7,7,7,7,3,0},
  {0,0,3,7,7,7,3,7,7,3,7,7,7,3,0,0},
  {0,0,0,3,7,7,3,7,7,3,7,7,3,0,0,0},
  {0,0,0,3,7,7,3,7,7,3,7,7,3,0,0,0},
  {0,0,3,7,7,7,7,7,7,7,7,7,7,3,0,0},
  {0,0,3,7,7,7,7,7,7,7,7,7,7,3,0,0},
  {0,3,7,7,7,7,7,3,3,7,7,7,7,7,3,0},
  {0,3,7,7,7,3,3,0,0,3,3,7,7,7,3,0},
  {3,7,7,3,3,0,0,0,0,0,0,3,3,7,7,3},
  {3,3,3,0,0,0,0,0,0,0,0,0,0,3,3,3}
};

// numbers which are displayed
byte numbers[11][5][3] = {
  { {1,1,1},
    {1,0,1},
    {1,0,1},
    {1,0,1},
    {1,1,1}},
    
  { {0,1,0},
    {0,1,0},
    {0,1,0},
    {0,1,0},
    {0,1,0}},
    
  { {1,1,1},
    {0,0,1},
    {1,1,1},
    {1,0,0},
    {1,1,1}},
    
  { {1,1,1},
    {0,0,1},
    {1,1,1},
    {0,0,1},
    {1,1,1}},
    
  { {1,0,1},
    {1,0,1},
    {1,1,1},
    {0,0,1},
    {0,0,1}},
    
  { {1,1,1},
    {1,0,0},
    {1,1,1},
    {0,0,1},
    {1,1,1}},
    
  { {1,1,1},
    {1,0,0},
    {1,1,1},
    {1,0,1},
    {1,1,1}},
    
  { {1,1,1},
    {0,0,1},
    {0,0,1},
    {0,0,1},
    {0,0,1}},
    
  { {1,1,1},
    {1,0,1},
    {1,1,1},
    {1,0,1},
    {1,1,1}},
    
  { {1,1,1},
    {1,0,1},
    {1,1,1},
    {0,0,1},
    {1,1,1}},
  
  // for convenience purposes: 10 -> 9 at end of game
  { {1,1,1},
    {1,0,1},
    {1,1,1},
    {0,0,1},
    {1,1,1}}
}; 

// debouncing
int buttonState[4];
int lastButtonState[4] = {LOW, LOW, LOW, LOW};
int reading[4];
unsigned long lastDebounceTime[4];
unsigned long debounceDelay = 5;

void setup() {
  strip_1.begin();
  strip_1.setBrightness(TABLE_BRIGHTNESS);
  strip_1.show(); // Initialize all pixels to 'off'
  strip_2.begin();
  strip_2.setBrightness(TABLE_BRIGHTNESS);
  strip_2.show(); // Initialize all pixels to 'off'
  strip_3.begin();
  strip_3.setBrightness(TABLE_BRIGHTNESS);
  strip_3.show(); // Initialize all pixels to 'off'
  strip_4.begin();
  strip_4.setBrightness(TABLE_BRIGHTNESS);
  strip_4.show(); // Initialize all pixels to 'off'
  randomSeed(analogRead(0));
  pinMode(4, OUTPUT);
  pinMode(5, OUTPUT);
  pinMode(6, OUTPUT);
  pinMode(7, OUTPUT);
  pinMode(8, INPUT);
  pinMode(9, INPUT);
  pinMode(10, INPUT);
  pinMode(11, INPUT);
  Serial.begin(9600);
  
}

byte mode = 0;
int rainbowCounter = 0;
int inactivityCounter = 0;
int demoCounter = 0;
byte drawCounter = 0;

void loop() {
  if(mode == 0) {
    epileppy();
  } else if(mode == 1) {
    checkers();
  } else if(mode == 2) {
    rainbow();
  } else if(mode == 3 ){
    drawImageMario();
  } else if(mode == 4) {
    drawImageStern();
  } else if(mode == 5) {
    showTetris();
  } else if(mode == 6) {
    showSnake();
  } else if(mode == 7) {
    showPong();
  }
  
  // Input handling
  unsigned long time = millis();
  while(millis() - time < 10) { // listen for button presses for 10 ms
    reading[0] = digitalRead(LEFT);
    reading[1] = digitalRead(RIGHT);
    reading[2] = digitalRead(DOWN);
    for(int i = 0; i < 3; i++) {
      if (reading[i] != lastButtonState[i]) {
        lastDebounceTime[i] = millis();
      }
      if ((millis() - lastDebounceTime[i]) > debounceDelay) {
        // whatever the reading is at, it's been there for longer
        // than the debounce delay, so take it as the actual current state:
    
        // if the button state has changed:
        if (reading[i] != buttonState[i]) {
          buttonState[i] = reading[i];
          
          if(i == 0 && buttonState[i] == HIGH) {
            mode = max(0,mode - 1);
            inactivityCounter = 0;
            myFill(0);
            time - 10;
          } else if(i == 1 && buttonState[i] == HIGH) {
            mode = min(7, mode + 1);
            inactivityCounter = 0;
            myFill(0);
            time - 10;
          } else if(i == 2 && buttonState[i] == HIGH) { // start a game
            if(mode == 5) {
              time - 10;
              startTetris();
            } else if (mode == 6) {
              time - 10;
              startSnake();
            } else if (mode == 7) {
              time - 10;
              startPong();
            }
            inactivityCounter = 0;
          }
        }
      }
      
      lastButtonState[i] = reading[i];
    }
  }
  
  // after a approx. 15 sec delay it will start to cycle through the mode to demonstrate the modes
  // should be removed for further use
  if(ENABLE_DEMO_MODE) {
    if(inactivityCounter > 300) {
      demoCounter++;
      if(demoCounter > 80) {
        myFill(0);
        mode = (mode + 1) % 8;
        demoCounter = 0;
      }
    }
    inactivityCounter = min(1501, inactivityCounter + 1);
  }
}

// Start screen for Pong
void showPong() {
  byte colorNr = 0;
  
  for(byte x = 0; x < SIZE; x++) {
    for(byte y = 0; y < SIZE; y++) {

      colorNr = image_pong[y][x];
      
     switch(colorNr) {
        case 0: myDraw(x,y,0); break;
        case 1: myDraw(x,y,WHITE); break;
      }
    }
  }
  myShow();
}

// Start screen for Snake
void showSnake() {
  byte colorNr = 0;
  
  for(byte x = 0; x < SIZE; x++) {
    for(byte y = 0; y < SIZE; y++) {

      colorNr = image_snake[y][x];
      
     switch(colorNr) {
        case 0: myDraw(x,y,0); break;
        case 1: myDraw(x,y,GREEN); break;
        case 2: myDraw(x,y,YELLOW); break;
        case 3: myDraw(x,y,RED); break;
      }
    }
  }
  myShow();
}

// Start screen for Tetris
void showTetris() {
  byte colorNr = 0;
  
  for(byte x = 0; x < SIZE; x++) {
    for(byte y = 0; y < SIZE; y++) {

      colorNr = image_tetris[y][x];
      
     switch(colorNr) {
        case 0: myDraw(x,y,0); break;
        case 1: myDraw(x,y,WHITE); break;
        case 2: myDraw(x,y,RED); break;
        case 3: myDraw(x,y,GREEN); break;
        case 4: myDraw(x,y,BLUE); break;
        case 5: myDraw(x,y,YELLOW); break;
        case 6: myDraw(x,y,MAGENTA); break;
        case 7: myDraw(x,y,TEAL); break;
      }
    }
  }
  myShow();
}

//Partymode: Rainbows
void rainbow() {
  for(int i=0; i < 512; i++) {
    myDraw(i, Wheel(i+(rainbowCounter*3) % 256));
  }
  rainbowCounter++;
  myShow();
}

// Input a value 0 to 255 to get a color value.
// The colours are a transition r - g - b - back to r.
uint32_t Wheel(byte WheelPos) {
  WheelPos = 255 - WheelPos;
  if(WheelPos < 85) {
    return strip_1.Color(255 - WheelPos * 3, 0, WheelPos * 3);
  }
  if(WheelPos < 170) {
    WheelPos -= 85;
    return strip_1.Color(0, WheelPos * 3, 255 - WheelPos * 3);
  }
  WheelPos -= 170;
  return strip_1.Color(WheelPos * 3, 255 - WheelPos * 3, 0);
}
// END: Rainbow

void theaterchase() {
  for(int i = 0; i < 512; i++) {
    myDraw()
  }
}

// Draw Mario
void drawImageMario() {
  byte colorNr = 0;
  
  for(byte x = 0; x < SIZE; x++) {
    for(byte y = 0; y < SIZE; y++) {

      colorNr = image_mario[y][x];
      
     switch(colorNr) {
        case 0: myDraw(x,y,WHITE); break;
        case 1: myDraw(x,y,MARIO_RED); break;
        case 2: myDraw(x,y,MARIO_BROWN); break;
        case 3: myDraw(x,y,strip_1.Color(0,0,0)); break;//NICHTS ;
        case 4: myDraw(x,y,MARIO_HAUT); break;
        case 5: myDraw(x,y,MARIO_BLUE); break;
        case 7: myDraw(x,y,MARIO_STERN_INNENGELB); break;
        case 8: myDraw(x,y,MARIO_KNOEPFE); break;
      }
    }
  }
  myShow();
}

// Draw Star
void drawImageStern() {
  byte colorNr = 0;
  
  for(byte x = 0; x < SIZE; x++) {
    for(byte y = 0; y < SIZE; y++) {

      colorNr = image_mario_stern[y][x];
      
     switch(colorNr) {
        case 0: myDraw(x,y,WHITE); break;
        case 1: myDraw(x,y,MARIO_RED); break;
        case 2: myDraw(x,y,MARIO_BROWN); break;
        case 3: myDraw(x,y,strip_1.Color(0,0,0)); break;//NICHTS ;
        case 4: myDraw(x,y,MARIO_HAUT); break;
        case 5: myDraw(x,y,MARIO_BLUE); break;
        case 7: myDraw(x,y,MARIO_STERN_INNENGELB); break;
        case 8: myDraw(x,y,MARIO_KNOEPFE); break;
      }
    }
  }
  myShow();
}

// Draw checkers board
void checkers() {
  myFill(0);
  for(byte x = 0; x < 16; x+=2) {
    for(byte y = 0; y < 16; y+=2) {
      if((x+y) % 4 == 0) {
        myDraw(x,y,WHITE);
        myDraw(x+1,y,WHITE);
        myDraw(x,y+1,WHITE);
        myDraw(x+1,y+1,WHITE);
      }
    }
  }
  myShow();
}

// Partymode
void epileppy() {
  for(byte x = 0; x < SIZE; x++) {
    for(byte y = 0; y < SIZE; y++) {
      myDraw(x,y,strip_1.Color(random(256),random(256),random(256)));
    }
  }
  myShow();
}

//Tetris building blocks
byte shapes[8][4][16]={
// i
{ {1, 1, 1, 1, 0, 0, 0, 0, 0, 0, 0, 0, 0, 0, 0, 0 },
{1, 0, 0,0,1, 0,  0, 0,1, 0,  0, 0, 1,0,  0, 0 },
{ 1, 1, 1, 1,0, 0, 0, 0,  0, 0, 0, 0, 0, 0, 0, 0 },
{ 1,0, 0, 0, 1,0,  0, 0,1, 0,  0, 0, 1,0,  0, 0 } },
// s
{ { 0, 1, 1, 0, 1, 1, 0, 0, 0, 0, 0, 0, 0, 0, 0, 0 },
{ 1, 0, 0, 0, 1, 1, 0, 0, 0, 1, 0, 0, 0, 0, 0, 0 },
{ 0, 1, 1, 0, 1, 1, 0, 0, 0, 0, 0, 0, 0, 0, 0, 0 },
{ 1, 0, 0, 0, 1, 1, 0, 0, 0, 1, 0, 0, 0, 0, 0, 0 } },
// z
{ { 1, 1, 0, 0, 0, 1, 1, 0, 0, 0, 0, 0, 0, 0, 0, 0 },
{ 0, 1, 0, 0, 1, 1, 0, 0, 1, 0, 0, 0, 0, 0, 0, 0 },
{ 1, 1, 0, 0, 0, 1, 1, 0, 0, 0, 0, 0, 0, 0, 0, 0 },
{ 0, 1, 0, 0, 1, 1, 0, 0, 1, 0, 0, 0, 0, 0, 0, 0 } },
// j
{ { 0, 1, 0, 0, 0, 1, 0, 0, 1, 1, 0, 0, 0, 0, 0, 0 },
{ 1, 0, 0, 0, 1, 1, 1, 0, 0, 0, 0, 0, 0, 0, 0, 0 },
{ 1, 1, 0, 0, 1, 0, 0, 0, 1, 0, 0, 0, 0, 0, 0, 0 },
{ 1, 1, 1, 0, 0, 0, 1, 0, 0, 0, 0, 0, 0, 0, 0, 0 } },
// o
{ { 1, 1, 0, 0, 1, 1, 0, 0, 0, 0, 0, 0, 0, 0, 0, 0 },
{ 1, 1, 0, 0, 1, 1, 0, 0, 0, 0, 0, 0, 0, 0, 0, 0 },
{ 1, 1, 0, 0, 1, 1, 0, 0, 0, 0, 0, 0, 0, 0, 0, 0 },
{ 1, 1, 0, 0, 1, 1, 0, 0, 0, 0, 0, 0, 0, 0, 0, 0 } },
// l
{ { 1, 0, 0, 0, 1, 0, 0, 0, 1, 1, 0, 0, 0, 0, 0, 0 },
{ 1, 1, 1, 0, 1, 0, 0, 0, 0, 0, 0, 0, 0, 0, 0, 0 },
{ 1, 1, 0, 0, 0, 1, 0, 0, 0, 1, 0, 0, 0, 0, 0, 0 },
{ 0, 0, 1, 0, 1, 1, 1, 0, 0, 0, 0, 0, 0, 0, 0, 0 } },
// _|
{ { 1, 1, 1, 0, 0, 0, 1, 0, 0, 0, 0, 0, 0, 0, 0, 0 },
{ 1, 1, 0, 0, 1, 0, 0, 0, 1, 0, 0, 0, 0, 0, 0, 0 },
{ 1, 0, 0, 0, 1, 1, 1, 0, 0, 0, 0, 0, 0, 0, 0, 0 },
{ 0, 1, 0, 0, 0, 1, 0, 0, 1, 1, 0, 0, 0, 0, 0, 0 } },
// t
{ { 0, 1, 0, 0, 1, 1, 1, 0, 0, 0, 0, 0, 0, 0, 0, 0 },
{ 0, 1, 0, 0, 1, 1, 0, 0, 0, 1, 0, 0, 0, 0, 0, 0 },
{ 1, 1, 1, 0, 0, 1, 0, 0, 0, 0, 0, 0, 0, 0, 0, 0 },
{ 1,0, 0, 0, 1, 1,0, 0,1, 0, 0, 0, 0, 0, 0, 0 } } };

byte current_block;

//Tetris
byte level;
byte blockType;
byte turnState;
byte blockX;
byte blockY;
byte gameOverTetrisFlag;
byte tetrismap[SIZE][SIZE];
int counter;

// initialize tetris
void startTetris() {
  level = 20;
  counter = 0;
  gameOverTetrisFlag = 0;
  newTetrismap();
  newblock();
  paintTetrismap();
  tetrisLoop();
}

// tetris' own loop
void tetrisLoop() {
  // Input handling
  
  reading[0] = digitalRead(RIGHT);
  reading[1] = digitalRead(LEFT);
  reading[2] = digitalRead(DOWN);
  reading[3] = digitalRead(TURN);
  for(int i = 0; i < 4; i++) {
    if (reading[i] != lastButtonState[i]) {
      lastDebounceTime[i] = millis();
    }
    if ((millis() - lastDebounceTime[i]) > debounceDelay) {
      // whatever the reading is at, it's been there for longer
      // than the debounce delay, so take it as the actual current state:
  
      // if the button state has changed:
      if (reading[i] != buttonState[i]) {
        buttonState[i] = reading[i];
        
        if(i == 3 && buttonState[i] == HIGH) {
          turn();
        }
      }
      
      if(i == 2 && buttonState[i] == HIGH) {
        down();
      } else if(i == 0 && buttonState[i] == HIGH) {
        left();
      } else if(i == 1 && buttonState[i] == HIGH) {
        right();
      }
    }
    
    lastButtonState[i] = reading[i];
  }
  
  // next tick is happening
  counter++;
  if(counter > level) {
    down();
    counter = 0;
  }
  paintTetrismap();
  delay(10);
  if(gameOverTetrisFlag) {
    gameoverTetris();
  } else {
    tetrisLoop();
  }
}

// turn the block
void turn() {
  byte tempturnState = turnState;
  turnState = (turnState + 1) % 4;
  if (collide(blockX, blockY, blockType, turnState) == 0) {
	  clearActiveBlock();
	  addBlock(blockX, blockY, blockType, turnState, 1);
	}
  if (collide(blockX, blockY, blockType, turnState) == 1) {
    turnState = tempturnState;
  }
}

// move block to the left
void left() {
  if(blockX>0) {
    if (collide(blockX - 1, blockY, blockType, turnState) == 0) {
      clearActiveBlock();
      blockX = blockX - 1;
      addBlock(blockX, blockY, blockType, turnState, 1);
    }
  }
}

// move block to the right
void right() {
  if(blockX<15) {
    if (collide(blockX + 1, blockY, blockType, turnState) == 0) {
      clearActiveBlock();
      blockX = blockX + 1;
      addBlock(blockX, blockY, blockType, turnState, 1);
    }
  }
}

// move block down (quicker)
void down() {
  if (collide(blockX, blockY + 1, blockType, turnState) == 0) {
    clearActiveBlock();
    blockY = blockY + 1;
    addBlock(blockX, blockY, blockType, turnState, 1);
  }
  else if (collide(blockX, blockY + 1, blockType, turnState) == 1) {
    clearActiveBlock();
    addBlock(blockX, blockY, blockType, turnState, random(2,8));
    delline();
    newblock();
  }
}

// checks if there are lines to delete
void delline() {
  byte linesToDelete[16];
  byte deletions = 0;
  for(byte y = 0; y < SIZE; y++) {
    byte countBlocks = 0;
    for(byte x = 0; x < SIZE; x++) {
      if(tetrismap[x][y] > 0) {
        countBlocks++;
      }
    }
    if(countBlocks == 16) { // full line
      linesToDelete[y] = 2;
      deletions++;
    } else if(countBlocks > 0) {
      linesToDelete[y] = 1;
    } else {
      linesToDelete[y] = 0;
    }
  }
  
  if(deletions > 0) {
    // animation
    for(byte count = 0; count < 5; count++) {
      for(byte y = 0; y < SIZE; y++) {
        if(linesToDelete[y] == 2) {
          for(byte x = 0; x < SIZE; x++) {
            tetrismap[x][y] = 1;
          }
        }
      }
      paintTetrismap();
      delay(100);
      for(byte y = 0; y < SIZE; y++) {
        if(linesToDelete[y] == 2) {
          for(byte x = 0; x < SIZE; x++) {
            tetrismap[x][y] = 0;
          }
        }
      }
      paintTetrismap();
      delay(100);
    }
    // move blocks down
    for(int i = 0; i < deletions; i++) {
      for(int y = SIZE - 1; y >= 0 ; y--) {
        if(linesToDelete[y] == 2) {
          for(int a = y; a > 0; a--) {
            for(byte x = 0; x < SIZE; x++) {
              tetrismap[x][a] = tetrismap[x][a-1];
            }
            linesToDelete[a] = linesToDelete[a-1];
          }
          // make it harder
          level = max(0,level - 1);
        }
      }
    }
  }
}

// consolidate block to map
void addBlock(byte x, byte y, byte blockType, byte turnState, byte status) {
  byte j = 0;
  for (byte a = 0; a < 4; a++) {
    for (byte b = 0; b < 4; b++) {
      if (tetrismap[x + b][y + a] == 0 && shapes[blockType][turnState][j] == 1) {
        tetrismap[x + b ][y + a] = status;
      }
      j++;
    }
  }
}

// removes active block from tetrismap
void clearActiveBlock() {
  for (byte x = 0; x < 4; x++) {
    for (byte y = 0; y < 4; y++) {
      if(tetrismap[blockX + x][blockY + y] == 1) {
        tetrismap[blockX + x][blockY + y] = 0;
      }
    }
  }
}

// collision detection
byte collide(byte x, byte y, byte blockType, byte turnState) {
  for (byte i = 0; i < 4; i++) {
    for (byte k = 0; k < 4; k++) {
      if (shapes[blockType][turnState][i * 4 + k] == 1) {
        if( (tetrismap[x + k][y + i] > 1) || // hits another block?
            (y+i > 15) || // hits the floor?
            (x+k > 15) ) // hits the wall?
        {
          return 1;
        }
      }
    }
  }
	return 0;
}

// clears tetrismap
void newTetrismap() {
  for (byte i = 0; i < SIZE; i++) {
    for (byte k = 0; k < SIZE; k++) {
      tetrismap[i][k] = 0;
    }
  }
}

// add a new random block at the top
void newblock() {
  blockType = (byte) ((random()) % 8);
  turnState = (byte) ((random()) % 4);
  blockX = 6;
  blockY = 0;
  addBlock(blockX, blockY, blockType, turnState, 1);
  if(collide(blockX, blockY, blockType, turnState) == 1) {
    gameOverTetrisFlag = 1;
  }
}

// paint the map to the LEDs
void paintTetrismap() {
  for (byte x = 0; x < SIZE; x++) {
    for (byte y = 0; y < SIZE; y++){
      switch (tetrismap[x][y]) {
      case 7:
        myDraw(x,y,MAGENTA);
        break;
      case 6:
        myDraw(x,y,TEAL);
        break;
      case 5:
        myDraw(x,y,GREEN);
        break;
      case 4:
        myDraw(x,y,YELLOW);
        break;
      case 3:
        myDraw(x,y,BLUE);
        break;
      case 2:
        myDraw(x,y,RED);
        break;
      case 1:
        myDraw(x,y,WHITE);
        break;
      default:
	      myDraw(x,y,0);
      }
    }
  }
  myShow();
}

// game over animation
void gameoverTetris() {
  for(byte count = 0; count < 10; count++) {
    for (byte x = 0; x < SIZE; x++) {
      for (byte y = 0; y < SIZE; y++){
        if(tetrismap[x][y] != 0) {
          tetrismap[x][y] = 2;
        }
      }
    }
    paintTetrismap();
    delay(200);
    for (byte x = 0; x < SIZE; x++) {
      for (byte y = 0; y < SIZE; y++){
        if(tetrismap[x][y] != 0) {
          tetrismap[x][y] = 1;
        }
      }
    }
    paintTetrismap();
    delay(200);
  }
}

//Pong
byte posPlayer1; // min 1, max 14
byte posPlayer2;
byte posBallX;
byte posBallY;
short ballDirX;
short ballDirY;
byte scorePlayer1;
byte scorePlayer2;
byte pongSpeed;
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

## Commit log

2017-06-24 Mat und Tools
2017-06-25 Schaltplan hinzugefügt
    [Schaltplan.fzz]
2017-06-25 Download-Link und Bild hinzugefügt
2017-06-28 Magneten Bilder
2017-06-29 Update README.md
    Update Material
2017-06-29 Eletronik und Finish angepasst
